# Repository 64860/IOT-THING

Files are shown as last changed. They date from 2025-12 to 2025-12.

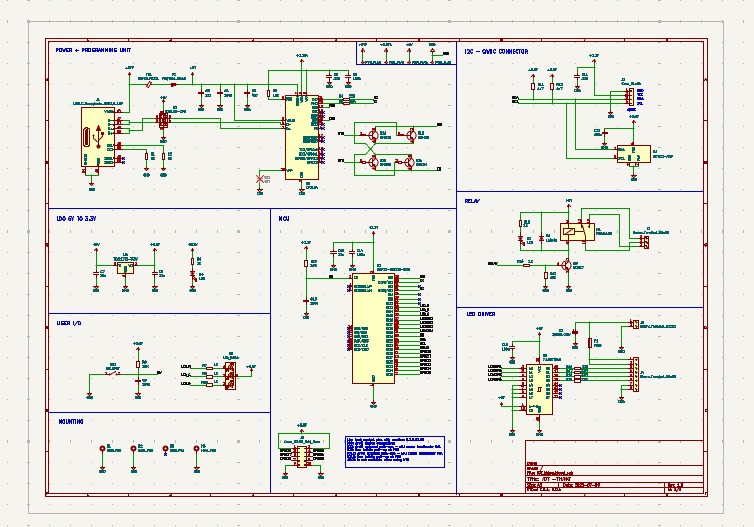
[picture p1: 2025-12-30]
Images/schematic.jpg

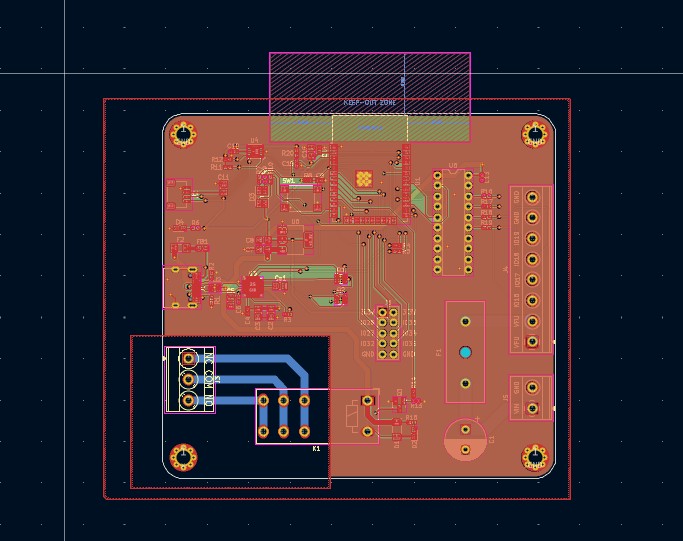
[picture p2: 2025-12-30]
Images/pcbnew2.jpg

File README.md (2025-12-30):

# ⚙️ IOT-THING

<div align="center">

<!-- TODO: Add a project logo if available in `Images/` or a custom design -->
<!-- ![Logo](Images/logo.png) -->







**A custom, compact 4-layer PCB design centered around the ESP32-WROOM-32 for robust IoT applications.**

</div>

## 📖 Overview

This project presents the comprehensive design files for a custom, compact 4-layer Printed Circuit Board (PCB). Engineered around the versatile ESP32-WROOM-32 microcontroller, this board is purpose-built for reliable performance in diverse IoT environments. It integrates advanced power management, industrial-grade switching capabilities, and high-speed USB communication, making it an ideal foundation for sophisticated embedded solutions. The design prioritizes compactness, robustness, and efficient signal routing inherent to its 4-layer construction.

## ✨ Key Features

*   **Custom 4-Layer PCB Design:** Optimized for component density, signal integrity, and reduced electromagnetic interference (EMI).
*   **ESP32-WROOM-32 Integration:** Leverages the powerful and feature-rich ESP32 for Wi-Fi, Bluetooth, and extensive I/O capabilities.
*   **Robust Power Management:** Designed for stable power delivery in varying operational conditions, accommodating industrial use cases.
*   **Industrial Switching Capabilities:** Incorporates circuitry for reliable switching of external loads, suitable for automation and control applications.
*   **High-Speed USB Communication:** Provides a fast and reliable interface for programming, debugging, and data exchange.
*   **Compact Form Factor:** Engineered for applications where space is at a premium without compromising functionality.

## 🛠️ Technology Stack

*   **EDA Software:** KiCad (v7 or later recommended)
*   **Microcontroller:** Espressif ESP32-WROOM-32 module
*   **Connectivity:** USB 2.0
*   **PCB Design:** 4-layer stackup

## 🖥️ Visuals

The `Images/` directory contains visual representations of the PCB, including renders, layout screenshots, or schematic snippets. The `3D models/` directory may contain 3D models of the board or specific components, useful for enclosure design or visualization.

<!-- TODO: Add actual screenshots from the `Images` directory, e.g.:

![PCB Top View](Images/pcb_top_view.png)

![PCB Schematic Overview](Images/schematic_overview.png)
-->

## 🚀 Getting Started

To explore or modify this PCB design, you will need the KiCad EDA Suite.

### Prerequisites

*   **KiCad EDA Suite**: Version 7.0 or newer is recommended for full compatibility with the project files.
    *   [Download KiCad](https://www.kicad.org/download/)

### Installation

1.  **Clone the repository**:
    ```bash
    git clone https://github.com/64860/IOT-THING.git
    cd IOT-THING
    ```

### Opening the Project

1.  **Launch KiCad.**
2.  From the KiCad project manager, go to `File` > `Open Project...` and navigate to the cloned repository.
3.  Select the `IOT_thing.kicad_pro` file and click `Open`.

This will load the entire project, including the schematic (`.kicad_sch`) and PCB layout (`.kicad_pcb`).

### Generating Fabrication Files

Once you have opened the project in KiCad, you can generate manufacturing output files:

1.  **Generate Gerbers for PCB manufacturing:**
    *   Open the `IOT_thing.kicad_pcb` file.
    *   Go to `File` > `Fabrication Outputs` > `Gerber files...`
    *   Configure output settings as required by your PCB manufacturer and click `Plot`.
2.  **Generate Bill of Materials (BOM):**
    *   Open the `IOT_thing.kicad_sch` file.
    *   Go to `Tools` > `Generate Bill of Materials...`
    *   Select a BOM generator script (e.g., `bom_csv_grouped_by_value.py`) and click `Generate`.
3.  **Generate Pick and Place files:**
    *   Open the `IOT_thing.kicad_pcb` file.
    *   Go to `File` > `Fabrication Outputs` > `Footprint Position (.pos) files...`
    *   Configure settings for your assembly house and click `Generate File`.

## 📁 Project Structure

```
IOT-THING/
├── 3D models/                  # 3D models of components or the board, useful for enclosure design.
├── IOT_thing-backups/          # Automatic backup files generated by KiCad.
├── Images/                     # Renders, photos, or diagrams related to the PCB design.
├── IOT_thing.kicad_pcb         # The main KiCad PCB layout file.
├── IOT_thing.kicad_prl         # KiCad project local settings file.
├── IOT_thing.kicad_pro         # The primary KiCad project file (opens the entire project).
├── IOT_thing.kicad_sch         # The main KiCad schematic file.
├── fp-info-cache               # KiCad's footprint information cache.
└── README.md                   # This README file.
```

## 👨‍💻 Firmware Development

This repository focuses on the hardware design. Firmware development for the ESP32-WROOM-32 would typically involve separate software projects using development environments like:

*   **Espressif IDF (ESP-IDF)**: Official IoT Development Framework for ESP32.
*   **Arduino IDE with ESP32 Core**: For easier development using the Arduino ecosystem.
*   **PlatformIO**: A professional embedded development platform.

## 🤝 Contributing

Contributions to improve the PCB design, suggest optimizations, or report issues are welcome! Please feel free to open a GitHub Issue or submit a Pull Request.

## 📄 License

This project currently does not have an explicit license file. Please contact the author for licensing information.

## 🙏 Acknowledgments

*   **KiCad EDA Suite:** For providing a powerful open-source tool for electronics design.
*   **Espressif Systems:** For the ESP32 series of microcontrollers.

## 📞 Support & Contact

-   🐛 Issues: [GitHub Issues](https://github.com/64860/IOT-THING/issues)

---

<div align="center">

**⭐ Star this repo if you find this hardware design helpful or inspiring!**

Made with ❤️ by [64860](https://github.com/64860)

</div>
```

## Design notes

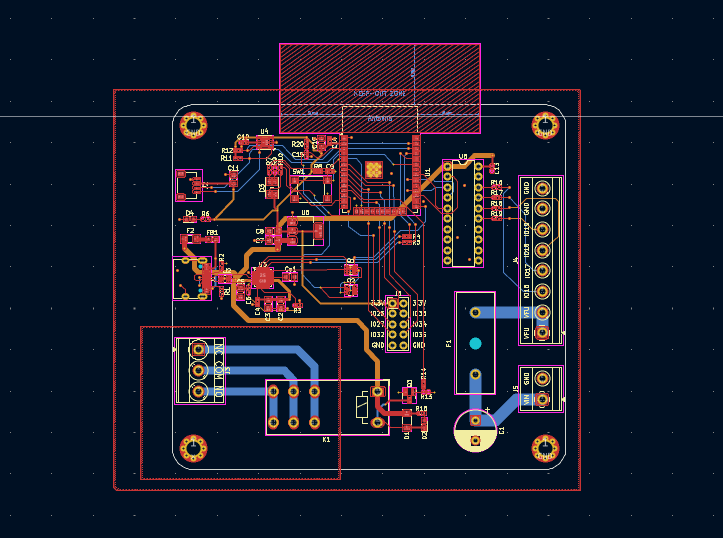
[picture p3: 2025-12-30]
Images/pcbnew.png

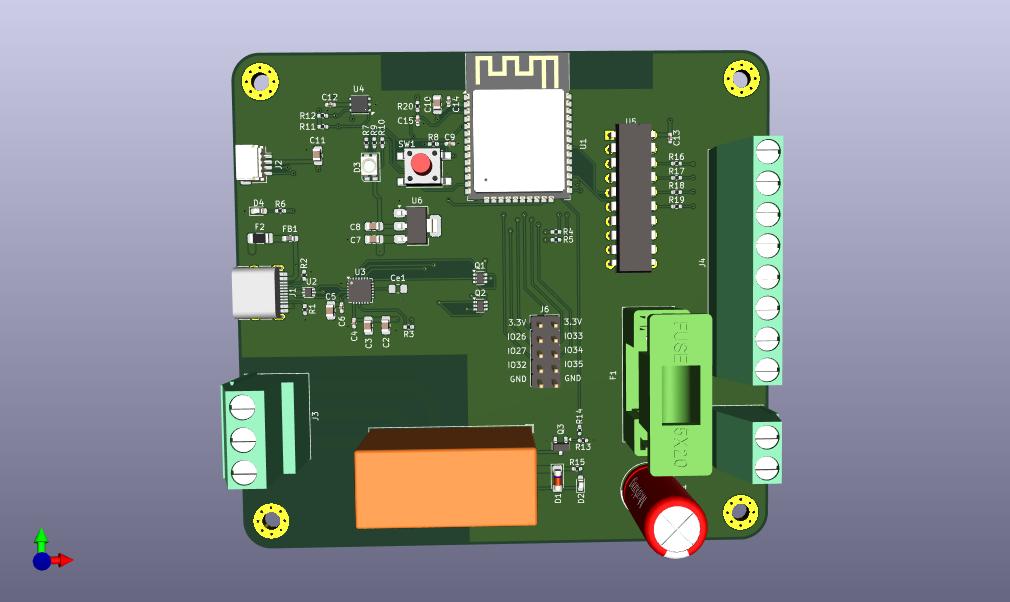
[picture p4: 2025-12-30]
Images/front.jpg

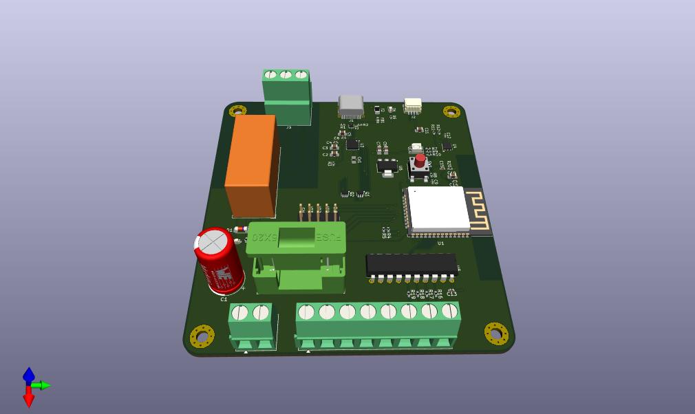
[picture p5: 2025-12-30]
Images/sideways1.jpg

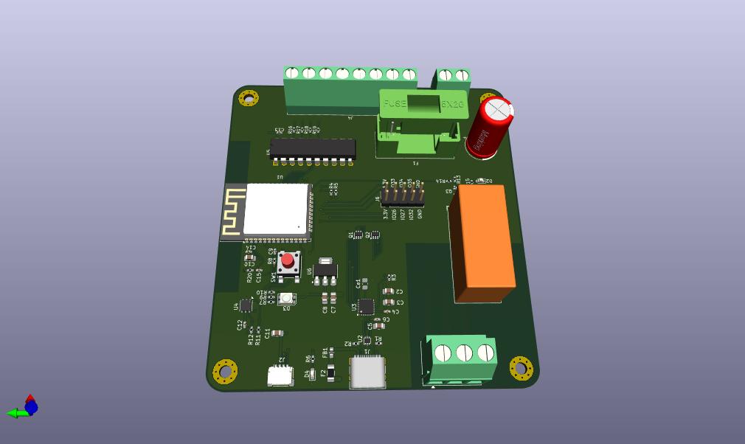
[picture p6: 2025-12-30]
Images/sideways2.jpg

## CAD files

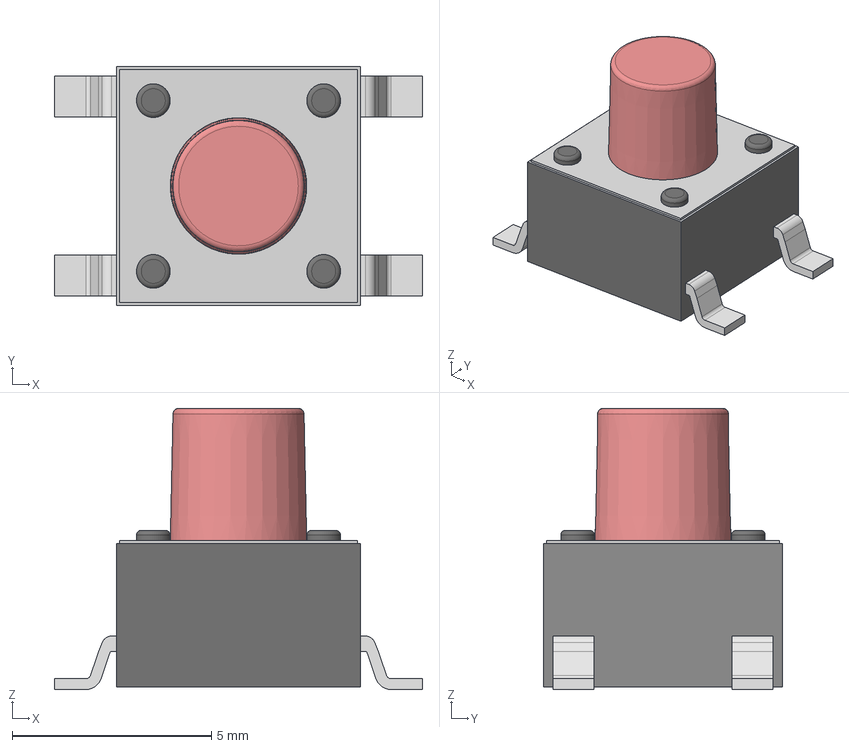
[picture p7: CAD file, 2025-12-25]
3D models/DTSM-63N-V-B.stp
9.25 x 5.99 x 7.07 mm

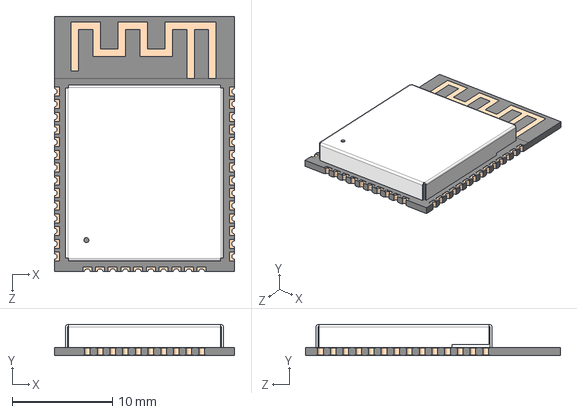
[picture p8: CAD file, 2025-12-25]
3D models/LIB_ESP32-WROOM-32E_M113EH3200PH3Q0_/ESP32-WROOM-32E_M113EH3200PH3Q0_/3D/ESP32-WROOM-32E_M113EH3200PH3Q0_.stp
18.0 x 3.10 x 25.5 mm

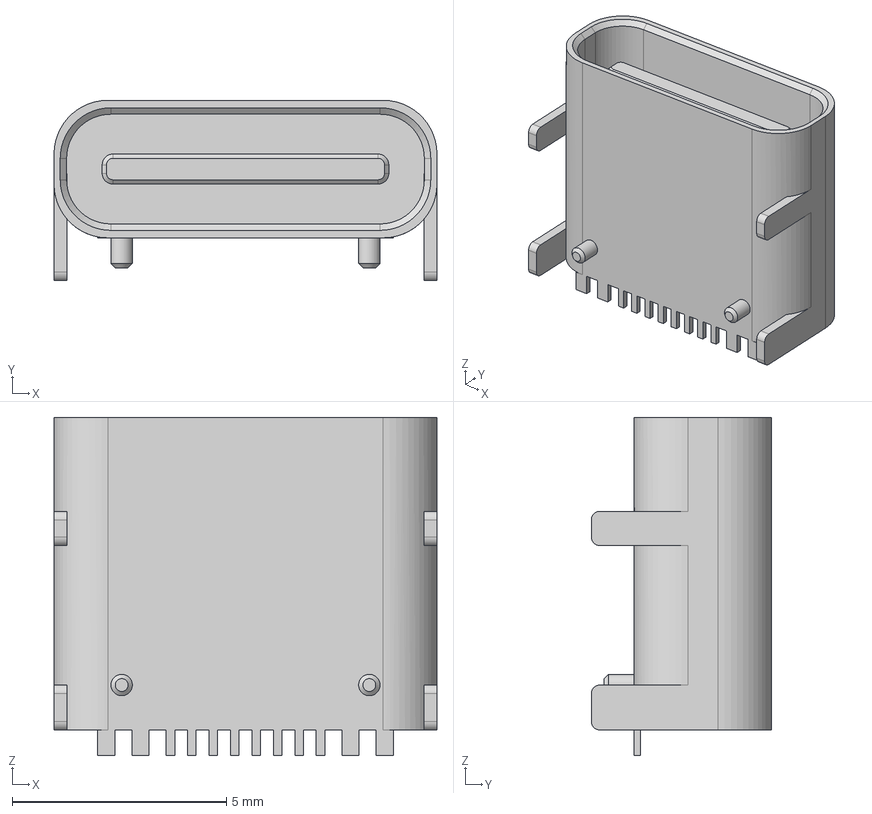
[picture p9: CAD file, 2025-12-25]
3D models/HRO TYPE-C-31-M-12.step
8.94 x 4.21 x 7.90 mm

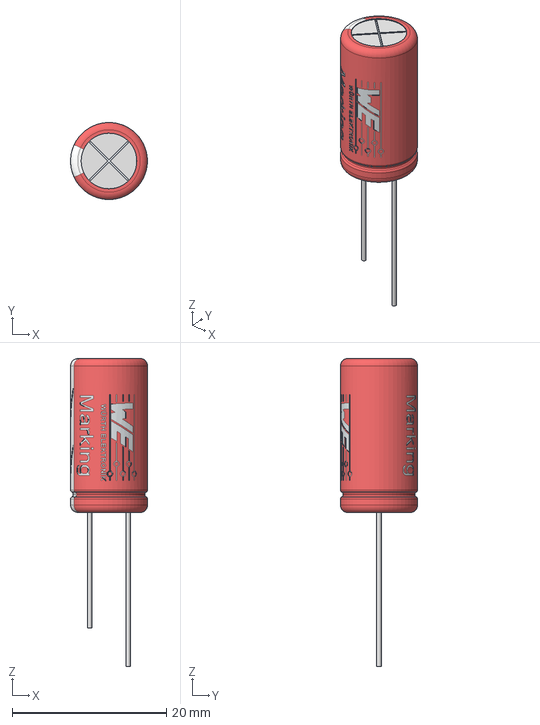
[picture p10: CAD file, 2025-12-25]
3D models/Download_STP_860010x750xx (rev1).stp
9.99 x 10.00 x 40.0 mm

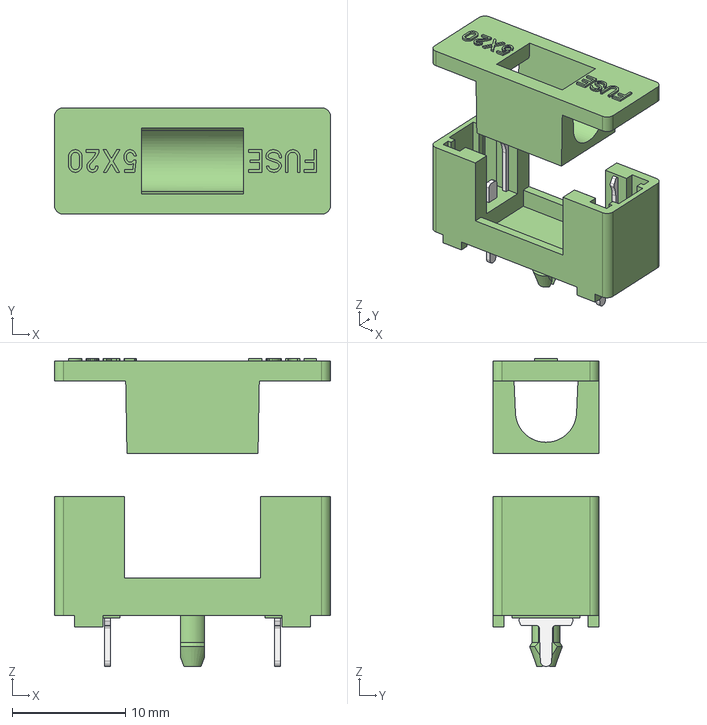
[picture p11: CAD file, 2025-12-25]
3D models/Download_STP_696105003002_rev1.stp
24.4 x 9.40 x 27.2 mm

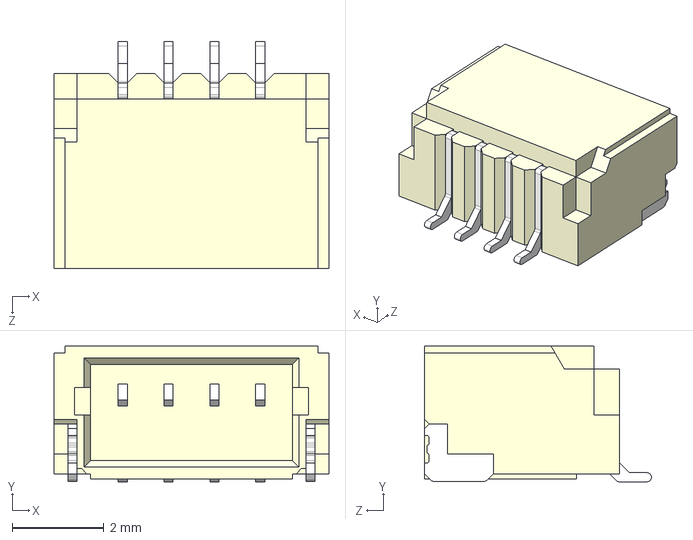
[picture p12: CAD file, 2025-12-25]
3D models/SM04B-SRSS-TB(LF)(SN)--3DModel-STEP-56544.STEP
6.00 x 2.96 x 4.95 mm

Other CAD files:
3D models/LIB_ESP32-WROOM-32E_M113EH3200PH3Q0_/ESP32-WROOM-32E_M113EH3200PH3Q0_/Allegro/esp32wroom32em113eh3200ph3q0.psm
3D models/LIB_ESP32-WROOM-32E_M113EH3200PH3Q0_/ESP32-WROOM-32E_M113EH3200PH3Q0_/DEHDL/esp32_wroom_32e_m113eh3200ph3q0_/chips/chips.prt

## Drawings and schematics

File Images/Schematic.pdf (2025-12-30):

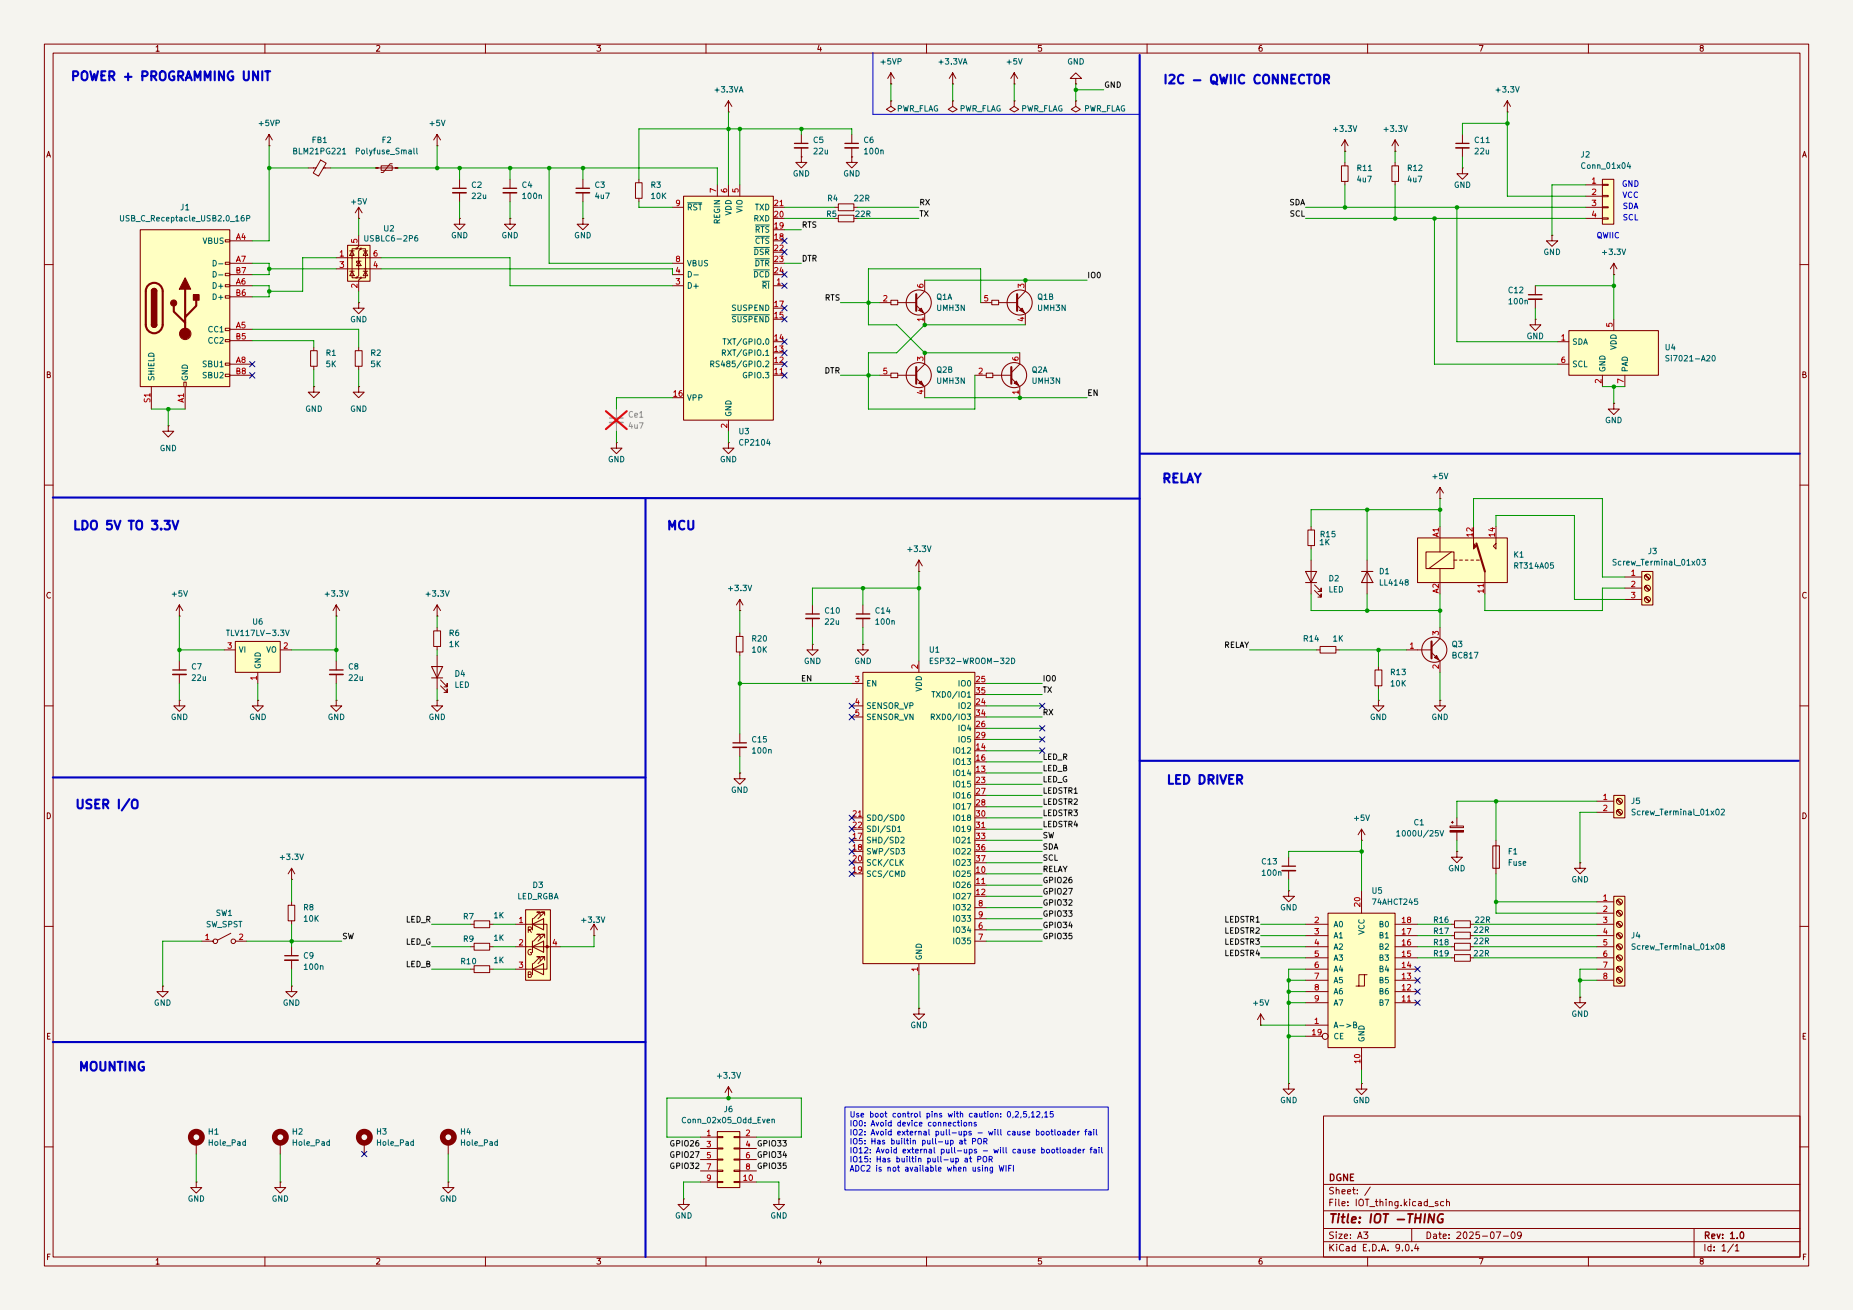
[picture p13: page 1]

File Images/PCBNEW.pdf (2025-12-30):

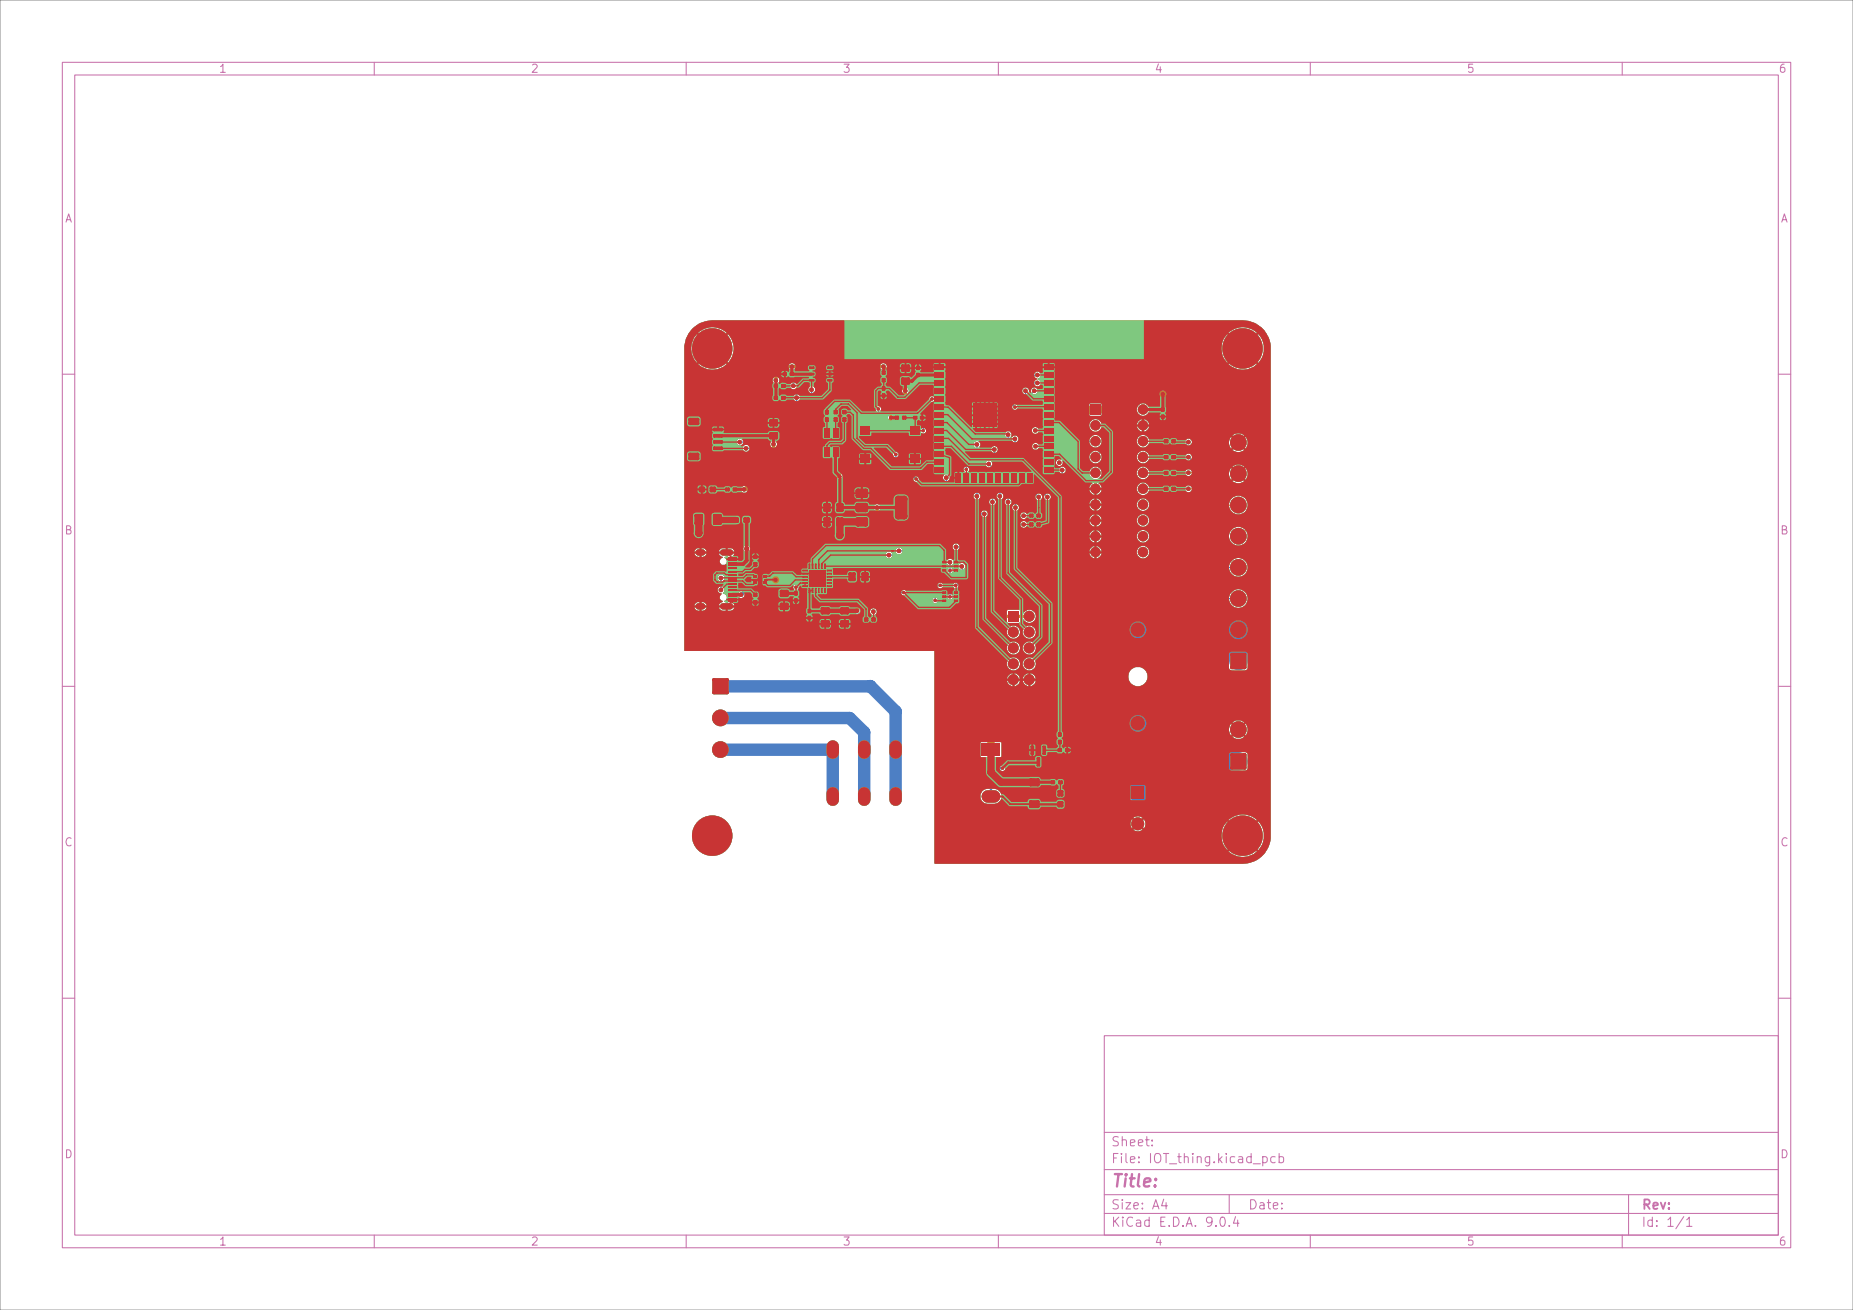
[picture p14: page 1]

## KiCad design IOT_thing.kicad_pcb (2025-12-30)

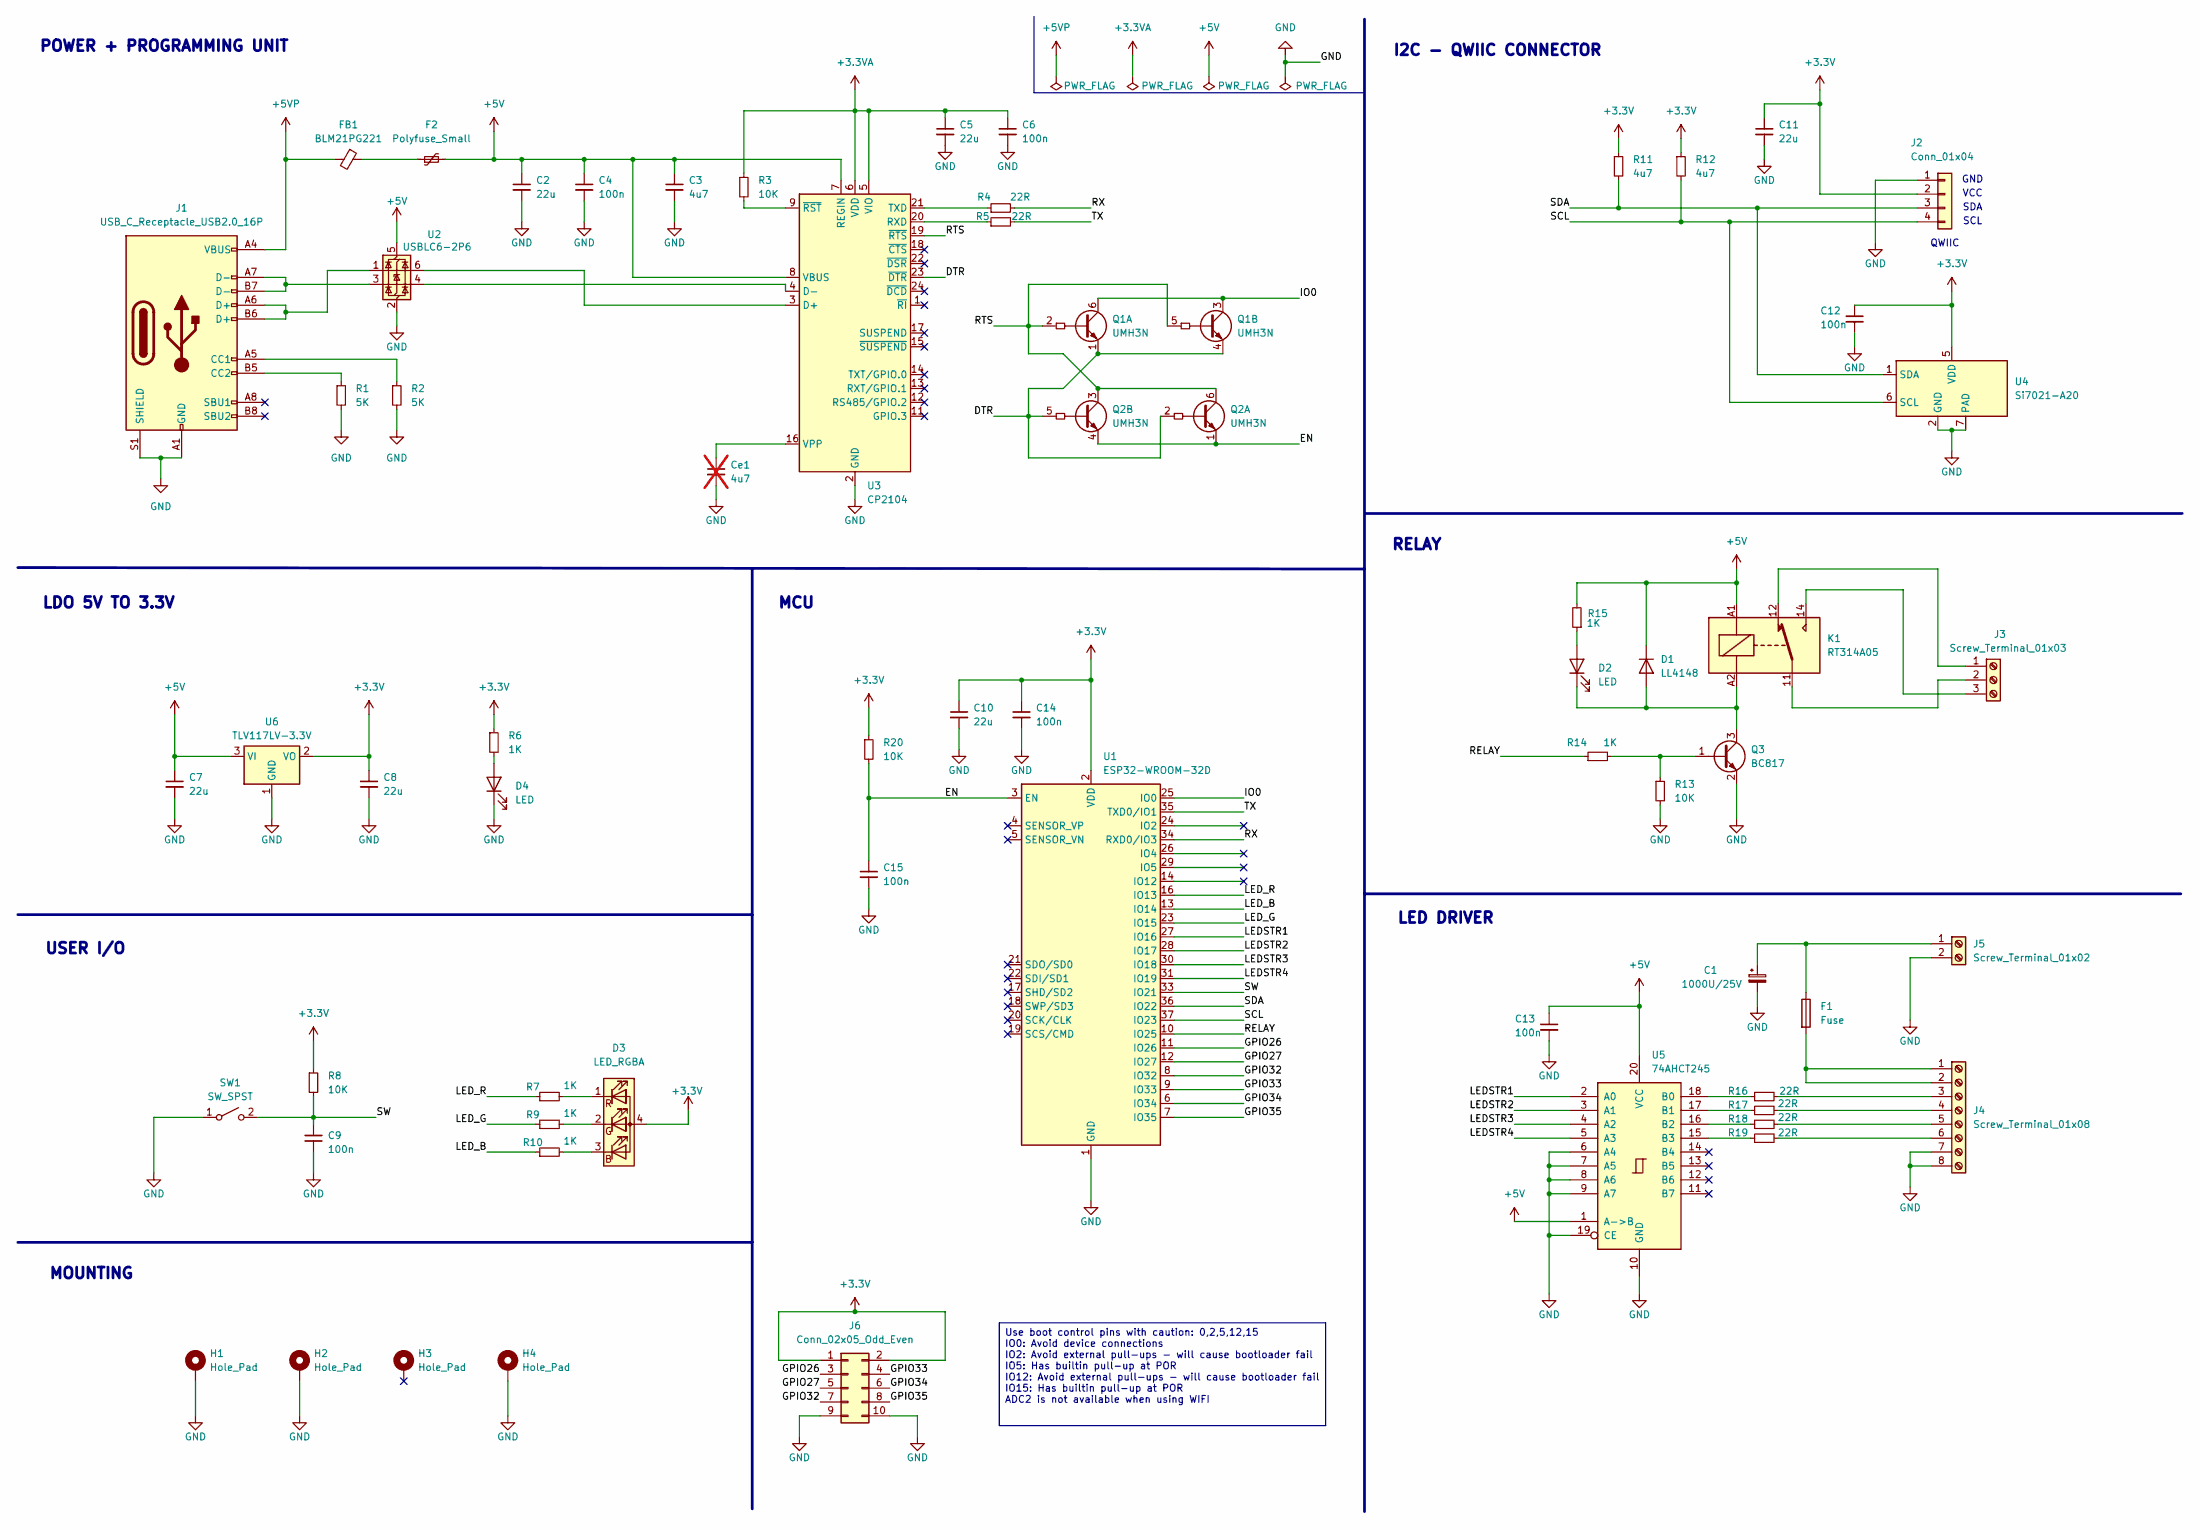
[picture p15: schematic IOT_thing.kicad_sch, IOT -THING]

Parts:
C1: 1000U/25V; CP_Radial_D10.0mm_P5.00mm
C2, C5, C7, C8, C10, C11: 22u; C_0805_2012Metric_Pad1.18x1.45mm_HandSolder
C3: 4u7; C_0805_2012Metric_Pad1.18x1.45mm_HandSolder
C4, C6, C9, C12, C13, C14, C15: 100n; C_0402_1005Metric_Pad0.74x0.62mm_HandSolder
Ce1: 4u7; C_0805_2012Metric_Pad1.18x1.45mm_HandSolder; not fitted
D1: LL4148; D_MiniMELF
D2, D4: LED; LED_0603_1608Metric_Pad1.05x0.95mm_HandSolder
D3: LED_RGBA; LED_RGB_Wuerth-PLCC4_3.2x2.8mm_150141M173100
F1: Fuse; FUSE_696105003002
F2: Polyfuse_Small; Fuse_1206_3216Metric_Pad1.42x1.75mm_HandSolder
FB1: BLM21PG221; L_0603_1608Metric_Pad1.05x0.95mm_HandSolder
H1, H2, H3, H4: Hole_Pad; MountingHole_3.2mm_M3_Pad_Via
J1: USB_C_Receptacle_USB2.0_16P; USB_C_Receptacle_HRO_TYPE-C-31-M-12
J2: Conn_01x04; JST_SH_SM04B-SRSS-TB_1x04-1MP_P1.00mm_Horizontal
J3: Screw_Terminal_01x03; TerminalBlock_Phoenix_MKDS-3-3-5.08_1x03_P5.08mm_Horizontal
J4: Screw_Terminal_01x08; TerminalBlock_Phoenix_MKDS-1,5-8_1x08_P5.00mm_Horizontal
J5: Screw_Terminal_01x02; TerminalBlock_Phoenix_MKDS-1,5-2-5.08_1x02_P5.08mm_Horizont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
J6: Conn_02x05_Odd_Even; PinHeader_2x05_P2.54mm_Vertical
K1: RT314A05; Relay_SPDT_Schrack-RT1-16A-FormC_RM5mm
Q1, Q2: UMH3N; SOT-363_SC-70-6
Q3: BC817; SOT-23
R1, R2: 5K; R_0402_1005Metric_Pad0.72x0.64mm_HandSolder
R3, R8, R13, R20: 10K; R_0402_1005Metric_Pad0.72x0.64mm_HandSolder
R4, R5, R16, R17, R18, R19: 22R; R_0402_1005Metric_Pad0.72x0.64mm_HandSolder
R6, R7, R9, R10, R14, R15: 1K; R_0402_1005Metric_Pad0.72x0.64mm_HandSolder
R11, R12: 4u7; R_0402_1005Metric_Pad0.72x0.64mm_HandSolder
SW1: SW_SPST; SW_Push_1P1T_NO_6x6mm_H9.5mm
U1: ESP32-WROOM-32D
U2: USBLC6-2P6; SOT-666
U3: CP2104; QFN-24-1EP_4x4mm_P0.5mm_EP2.6x2.6mm
U4: Si7021-A20; DFN-6-1EP_3x3mm_P1mm_EP1.5x2.4mm
U5: 74AHCT245; DIP-20_W7.62mm
U6: TLV117LV-3.3V; SOT-223-3_TabPin2

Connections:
+3.3V: C8.1, C10.1, C11.1, C12.1, C14.1, D3.4 (A), J2.2, J6.1, J6.2, R6.1, R8.1, R11.1, R12.1, R20.1, U1.2 (VDD), U4.5 (VDD), U6.2 (VO)
+3.3VA: C5.1, C6.1, R3.1, U3.5 (VIO), U3.6 (VDD)
+5V: C2.1, C3.1, C4.1, C7.1, C13.1, D1.1 (K), F2.2, K1.A1, R15.2, U2.5 (VBUS), U3.7 (REGIN), U3.8 (VBUS), U5.1 (A->B), U5.20 (VCC), U6.3 (VI)
+5VP: FB1.2, J1.A4 (VBUS), J1.A9 (VBUS), J1.B4 (VBUS), J1.B9 (VBUS)
/DTR: Q1.1 (E1), Q1.4 (E2), Q2.2 (B1), Q2.5 (B2), U3.23 (~DTR)
/EN: C15.1, Q2.1 (E1), Q2.4 (E2), R20.2, U1.3 (EN)
/GPIO26: J6.3, U1.11 (IO26)
/GPIO27: J6.5, U1.12 (IO27)
/GPIO32: J6.7, U1.8 (IO32)
/GPIO33: J6.4, U1.9 (IO33)
/GPIO34: J6.6, U1.6 (IO34)
/GPIO35: J6.8, U1.7 (IO35)
/IO0: Q1.3 (C2), Q1.6 (C1), U1.25 (IO0)
/LEDSTR1: U1.27 (IO16), U5.2 (A0)
/LEDSTR2: U1.28 (IO17), U5.3 (A1)
/LEDSTR3: U1.30 (IO18), U5.4 (A2)
/LEDSTR4: U1.31 (IO19), U5.5 (A3)
/LED_B: R10.1, U1.13 (IO14)
/LED_G: R9.1, U1.23 (IO15)
/LED_R: R7.1, U1.16 (IO13)
/RELAY: R14.1, U1.10 (IO25)
/RTS: Q1.2 (B1), Q1.5 (B2), Q2.3 (C2), Q2.6 (C1), U3.19 (~RTS)
/RX: R4.2, U1.34 (RXD0/IO3)
/SCL: J2.4, R12.2, U1.37 (IO23), U4.6 (SCL)
/SDA: J2.3, R11.2, U1.36 (IO22), U4.1 (SDA)
/SW: C9.1, R8.2, SW1.2 (B), U1.33 (IO21)
/TX: R5.2, U1.35 (TXD0/IO1)
GND: C1.2, C2.2, C3.2, C4.2, C5.2, C6.2, C7.2, C8.2, C9.2, C10.2, C11.2, C12.2, C13.2, C14.2, C15.2, Ce1.2, D4.1 (K), H1.1, H2.1, H4.1, J1.A1 (GND), J1.A12 (GND), J1.B1 (GND), J1.B12 (GND), J1.S1 (SHIELD), J2.1, J4.7, J4.8, J5.2, J6.9, J6.10, Q3.2 (E), R1.2, R2.2, R13.2, SW1.1 (A), U1.1 (GND), U1.15 (GND), U1.38 (GND), U1.39 (GND), U2.2 (GND), U3.2 (GND), U3.25 (GND), U4.2 (GND), U4.7 (PAD), U5.6 (A4), U5.7 (A5), U5.8 (A6), U5.9 (A7), U5.10 (GND), U5.19 (CE), U6.1 (GND)
unnamed: D1.2 (A), D2.1 (K), K1.A2, Q3.3 (C)
unnamed: D2.2 (A), R15.1
unnamed: D3.3 (BK), R10.2
unnamed: D3.2 (GK), R9.2
unnamed: D3.1 (RK), R7.2
unnamed: D4.2 (A), R6.2
unnamed: F2.1, FB1.1
unnamed: J1.A5 (CC1), R2.1
unnamed: J1.B5 (CC2), R1.1
unnamed: J1.A6 (D+), J1.B6 (D+), U2.1 (I/O1)
unnamed: J1.A7 (D-), J1.B7 (D-), U2.3 (I/O2)
unnamed: J3.1, K1.12
unnamed: J3.2, K1.11
unnamed: J3.3, K1.14
unnamed: F1.2, J4.1, J4.2
unnamed: J4.3, R16.2
unnamed: J4.4, R17.2
unnamed: J4.5, R18.2
unnamed: J4.6, R19.2
unnamed: C1.1, F1.1, J5.1
unnamed: Q3.1 (B), R13.1, R14.2
unnamed: U2.6 (I/O1), U3.3 (D+)
unnamed: U2.4 (I/O2), U3.4 (D-)
unnamed: R5.1, U3.20 (RXD)
unnamed: R4.1, U3.21 (TXD)
unnamed: Ce1.1, U3.16 (VPP)
unnamed: R3.2, U3.9 (~RST)
unnamed: R16.1, U5.18 (B0)
unnamed: R17.1, U5.17 (B1)
unnamed: R18.1, U5.16 (B2)
unnamed: R19.1, U5.15 (B3)

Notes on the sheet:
LED DRIVER
MOUNTING
SDA
GND
LDO 5V TO 3.3V
SCL
RELAY
USER I/O
MCU
QWIIC
POWER + PROGRAMMING UNIT
VCC
I2C - QWIIC CONNECTOR
Use boot control pins with caution: 0,2,5,12,15 IO0: Avoid device connections IO2: Avoid external pull-ups - will cause bootloader fail IO5: Has builtin pull-up at POR IO12: Avoid external pull-ups - will cause bootloader fail IO15: Has builtin pull-up at POR ADC2 is not available when using WIFI

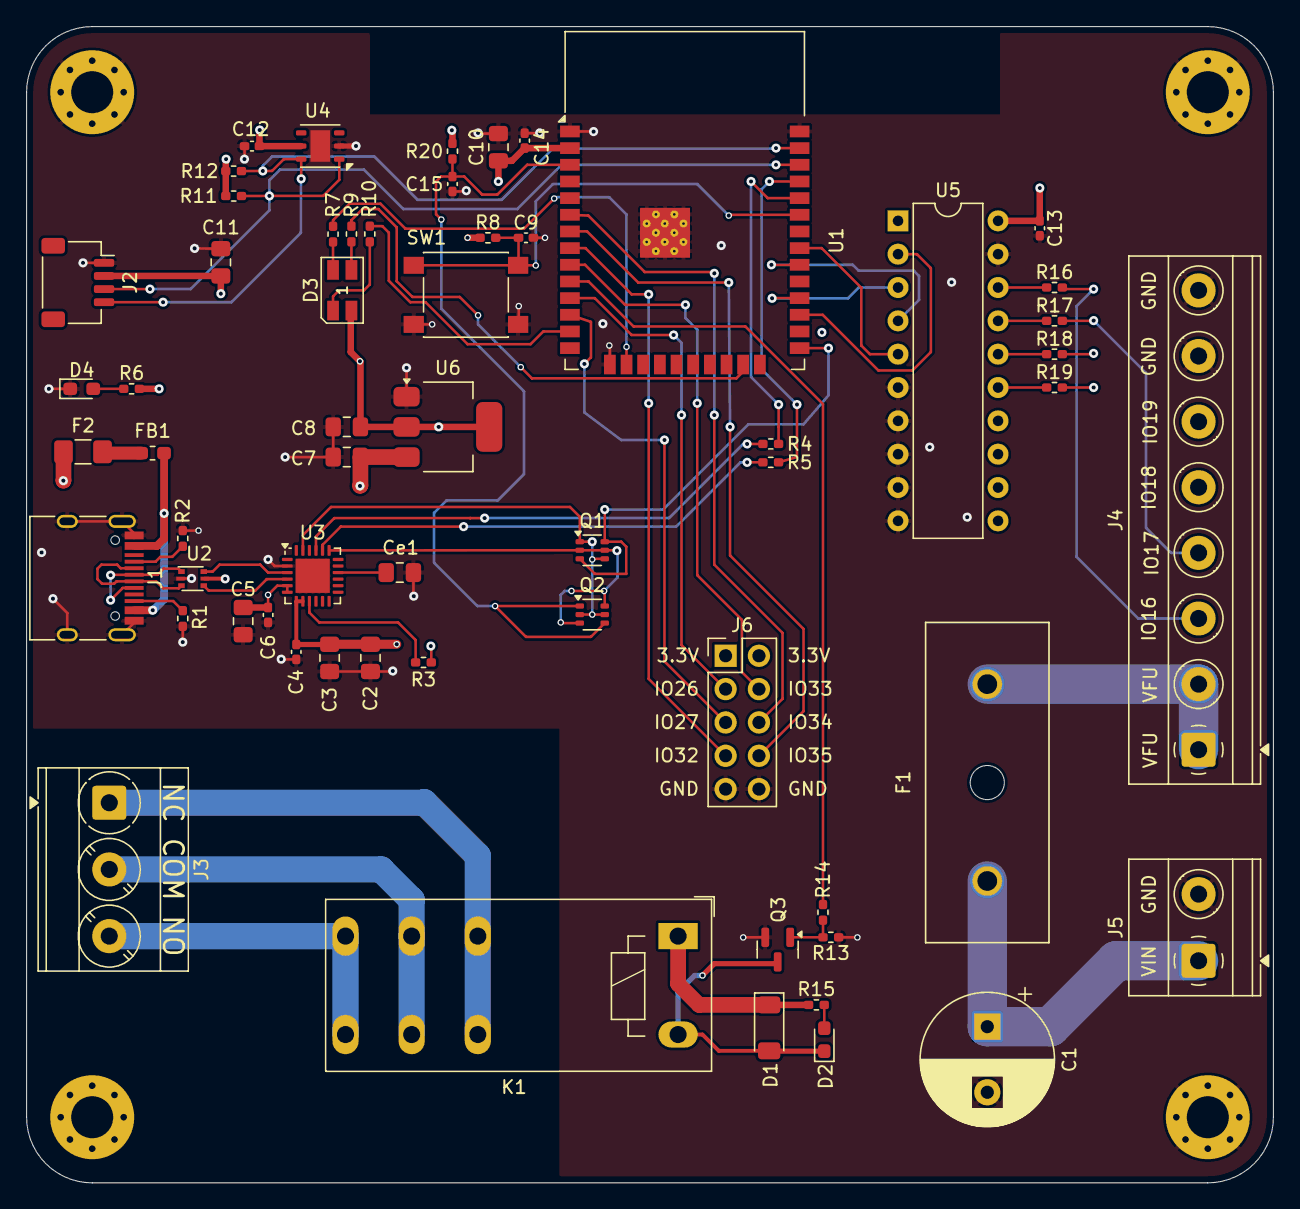
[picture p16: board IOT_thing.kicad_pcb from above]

Board: 4 copper layers, 95.0 x 88.1 mm, 64 parts (0 on the bottom side), 59 nets.

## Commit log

2025-07-09 Added components
    [IOT_thing.kicad_pcb, IOT_thing.kicad_sch]
2025-08-12 Placed all components
    [IOT_thing.kicad_sch]
2025-08-12 Edited the USBC symbol
    [IOT_thing.kicad_sch]
2025-08-12 Finished wiring the programming interface
    [IOT_thing.kicad_sch]
2025-08-12 Finished the power supply
    [IOT_thing.kicad_sch]
2025-08-12 Finished wiring the I2C part
    [IOT_thing.kicad_sch]
2025-08-12 Finished wiring the relay module
    [IOT_thing.kicad_sch]
2025-08-12 Finished wiring the ledstrip part
    [IOT_thing.kicad_sch]
2025-08-14 Completed commenting on the sheet and did annotations
    [IOT_thing.kicad_sch]
2025-08-25 Completed adding footprints
    [IOT_thing.kicad_sch]
2025-08-25 Started laying out the components
    [IOT_thing.kicad_pcb, IOT_thing.kicad_sch]
2025-12-25 Updated some footprints and 3d models
    [Download_STP_696105003002_rev1.stp, Download_STP_860010x750xx (rev1).stp, EDI2CAP.CFG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]
2025-12-25 Finalised updating all the 3d models
    [DTSM-63N-V-B.stp, IOT_thing.kicad_pcb]
2025-12-25 Finished arranging the components
    [IOT_thing.kicad_pcb]
2025-12-26 Arranged the layout and finalised the silkscreen
    [IOT_thing.kicad_pcb]
2025-12-30 Finalised the project
    [IOT_thing.kicad_pcb, IOT_thing.kicad_sch]
2025-12-30 Add README.md for ESP32-WROOM-32 project
    Added detailed project overview, technical specifications, and repository structure for the ESP32-WROOM-32 Multilayer Control Hub.
